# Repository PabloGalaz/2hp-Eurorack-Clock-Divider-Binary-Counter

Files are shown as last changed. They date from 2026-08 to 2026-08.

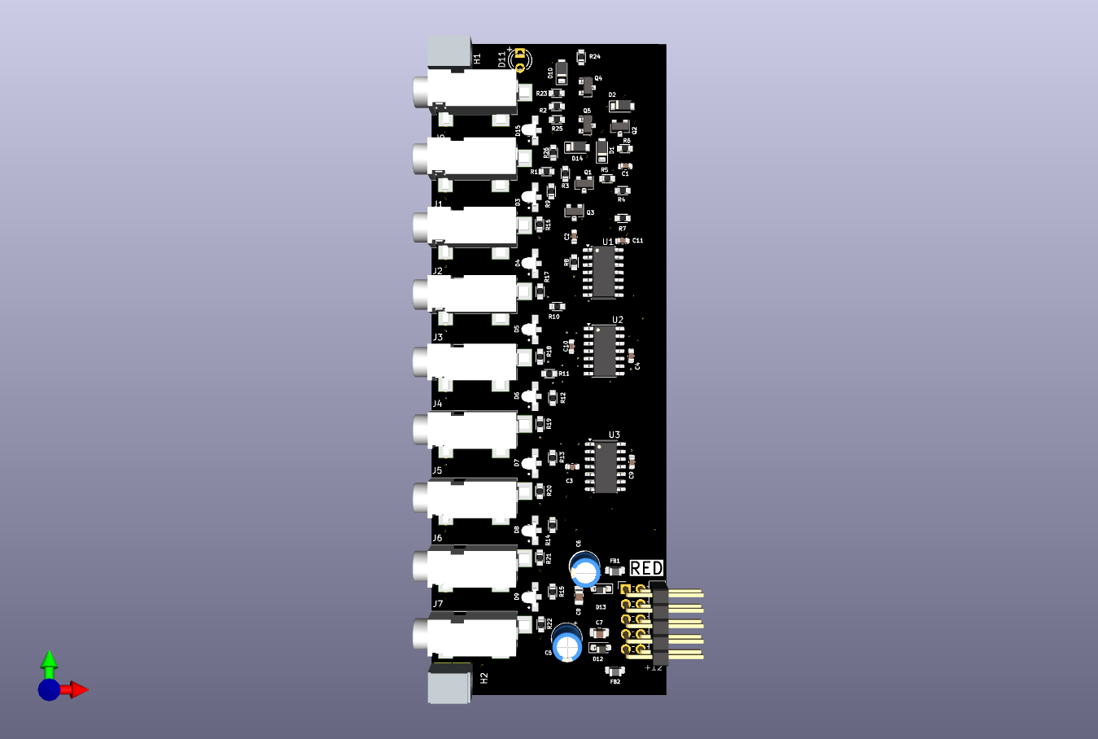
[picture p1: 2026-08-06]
Images/Clock_Div_Bin_Counter-2HP_V1_BOARD.png

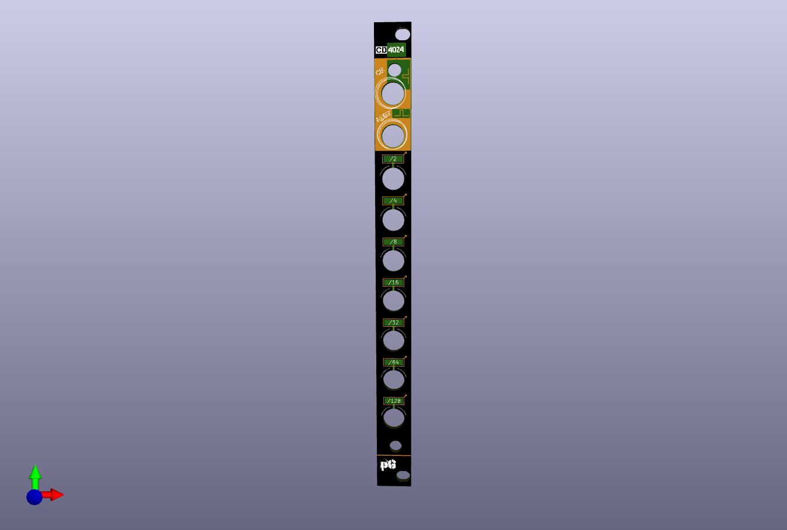
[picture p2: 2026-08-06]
Images/Clock_Div_Bin_Counter-2HP_V1_PANEL.png

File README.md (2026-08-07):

# 2hp-Eurorack-Clock-Divider-Binary-Counter

Slim CD4024-based Eurorack Clock Divider/Binary Counter derived from a schematic by PolyKit (https://polykit.rocks/eurorack-clock-divider-module-modular-synth-diy/), with the following differences:

- 2hp (instead of 4hp)
- Mostly SMD components (0603)
- Added /128 output
- Added LED for clock input (through-hole, bent; watch video)
- Only one board

The PCB layout was inspired by the PCB layout of Uncertainty, by OAM (https://github.com/oamodular/uncertainty.git)

Version 2 is the only one that has been manufactured and tested. This version has a footprint error that can be fixed by carefully bending the legs of the five MMBT3904 transistors (SOT-23-3) and soldering them upside down (!). It's easier than it sounds, and it will work. Version 3 has that error fixed, but has not been tested yet.

BUILD THIS AT YOUR OWN RISK. FILES PROVIDED "AS IS", WITHOUT WARRANTY OF ANY KIND.

Watch the video (https://www.youtube.com/shorts/lrMSy79it8Q)

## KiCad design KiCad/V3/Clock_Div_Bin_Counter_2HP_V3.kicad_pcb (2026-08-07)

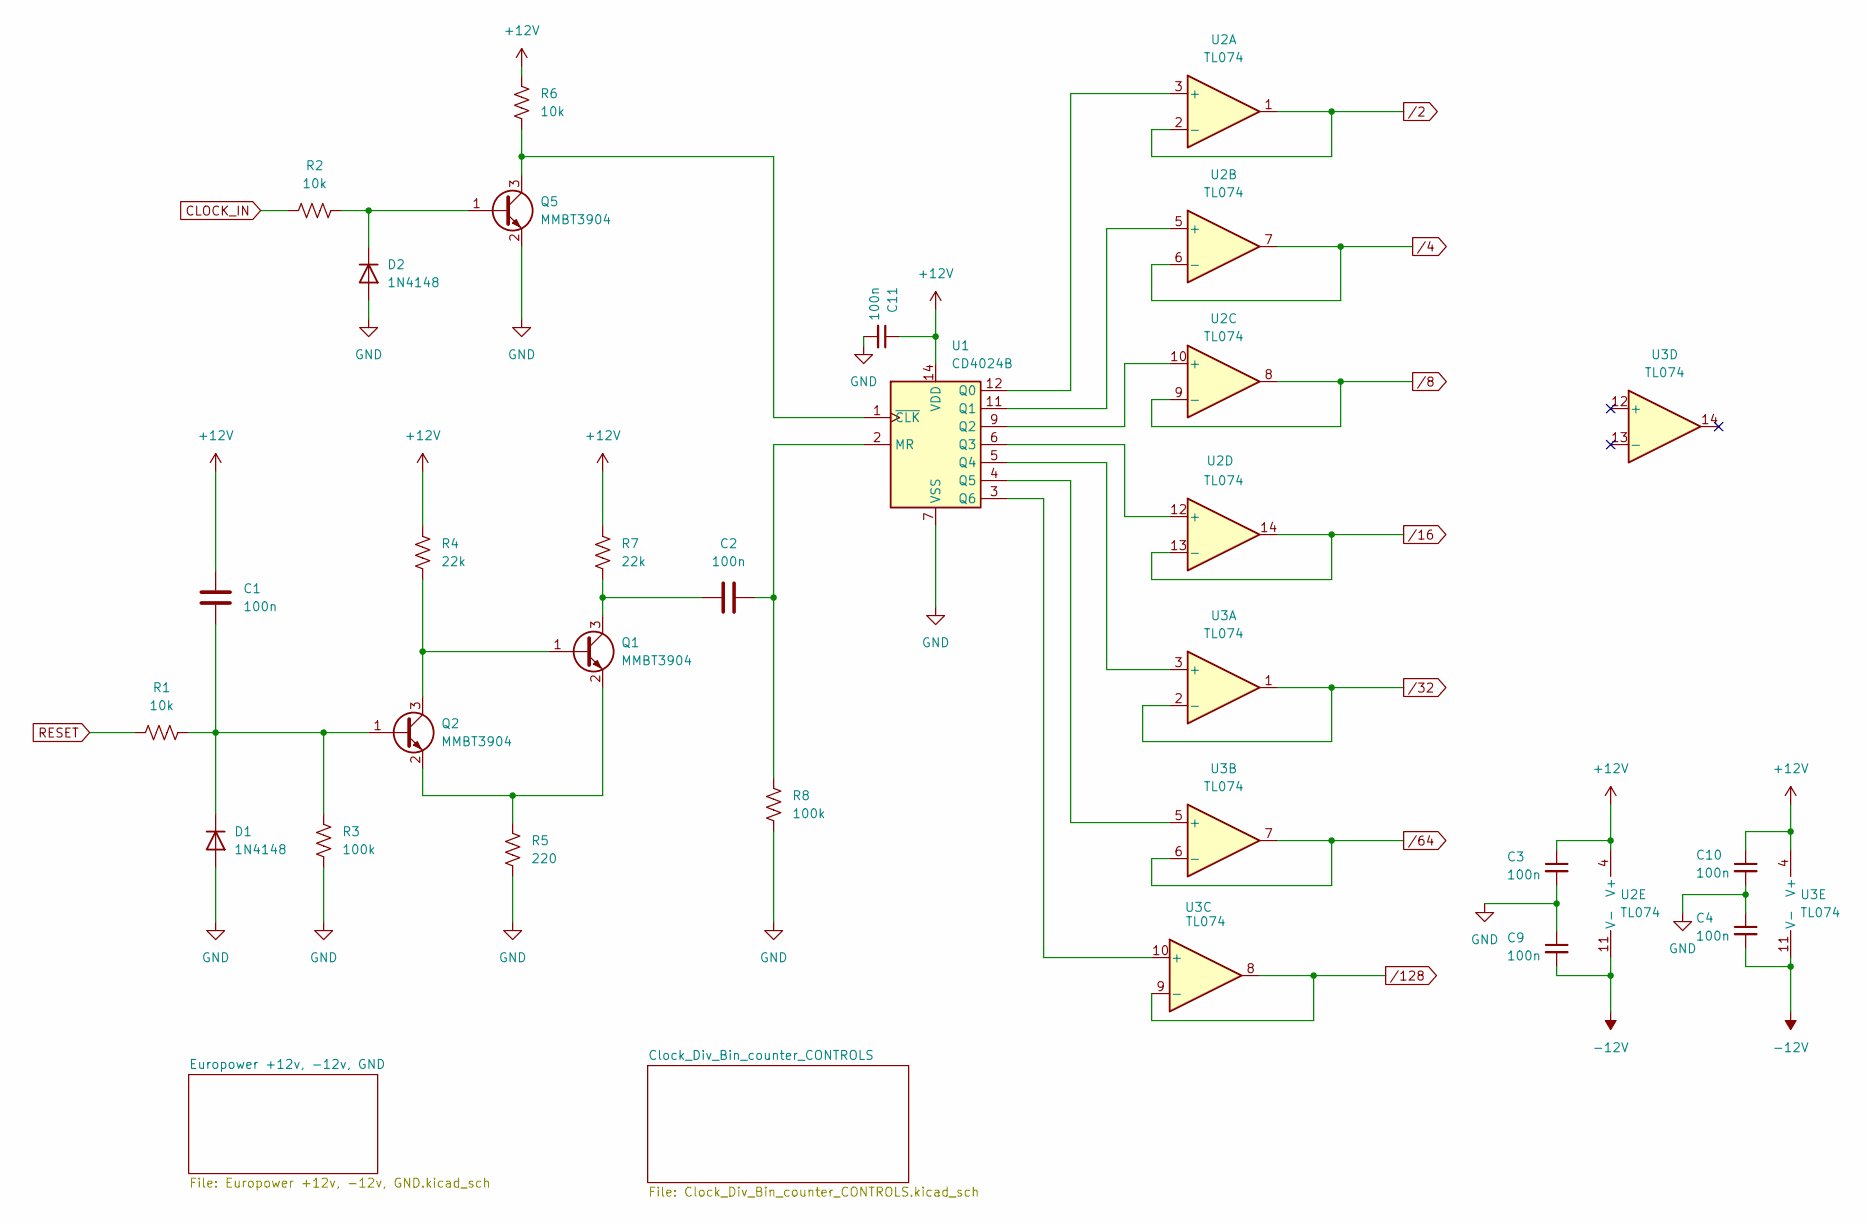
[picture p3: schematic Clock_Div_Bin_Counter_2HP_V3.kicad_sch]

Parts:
C1, C2, C3, C4, C9, C10, C11: 100n; C_0603_1608Metric
D1, D2: 1N4148; Nexperia_CFP3_SOD-123W
Q1, Q2, Q5: MMBT3904; SOT-23
R1, R2, R6: 10k; R_0603
R3, R8: 100k; R_0603
R4, R7: 22k; R_0603
R5: 220; R_0603
U1: CD4024B; SOIC-14_3.9x8.7mm_P1.27mm
U2, U3: TL074; SOIC-14_3.9x8.7mm_P1.27mm

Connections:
+12V: C1.1, C3.1, C10.1, C11.1, R4.2, R6.2, R7.2, U1.14 (VDD), U2.4 (V+), U3.4 (V+); also elsewhere on the board
-12V: C4.2, C9.2, U2.11 (V-), U3.11 (V-); also elsewhere on the board
CLOCK_IN: R2.1; also elsewhere on the board
GND: C3.2, C4.1, C9.1, C10.2, C11.2, D1.2 (A), D2.2 (A), Q5.2 (E), R3.1, R5.1, R8.1, U1.7 (VSS); also elsewhere on the board
unnamed: C1.2, D1.1 (K), Q2.1 (B), R1.2, R3.2
unnamed: D2.1 (K), Q5.1 (B), R2.2
unnamed: Q1.1 (B), Q2.3 (C), R4.1
unnamed: C2.1, Q1.3 (C), R7.1
unnamed: Q1.2 (E), Q2.2 (E), R5.2
unnamed: Q5.3 (C), R6.1, U1.1 (~CLK)
unnamed: C2.2, R8.2, U1.2 (MR)
unnamed: U1.12 (Q0), U2.3 (+)
unnamed: U1.11 (Q1), U2.5 (+)
unnamed: U1.9 (Q2), U2.10 (+)
unnamed: U1.6 (Q3), U2.12 (+)
unnamed: U1.5 (Q4), U3.3 (+)
unnamed: U1.4 (Q5), U3.5 (+)
unnamed: U1.3 (Q6), U3.10 (+)
RESET: R1.1; also elsewhere on the board
/2: U2.1, U2.2 (-); also elsewhere on the board
/4: U2.6 (-), U2.7; also elsewhere on the board
/8: U2.8, U2.9 (-); also elsewhere on the board
/16: U2.13 (-), U2.14; also elsewhere on the board
/32: U3.1, U3.2 (-); also elsewhere on the board
/64: U3.6 (-), U3.7; also elsewhere on the board
/128: U3.8, U3.9 (-); also elsewhere on the board

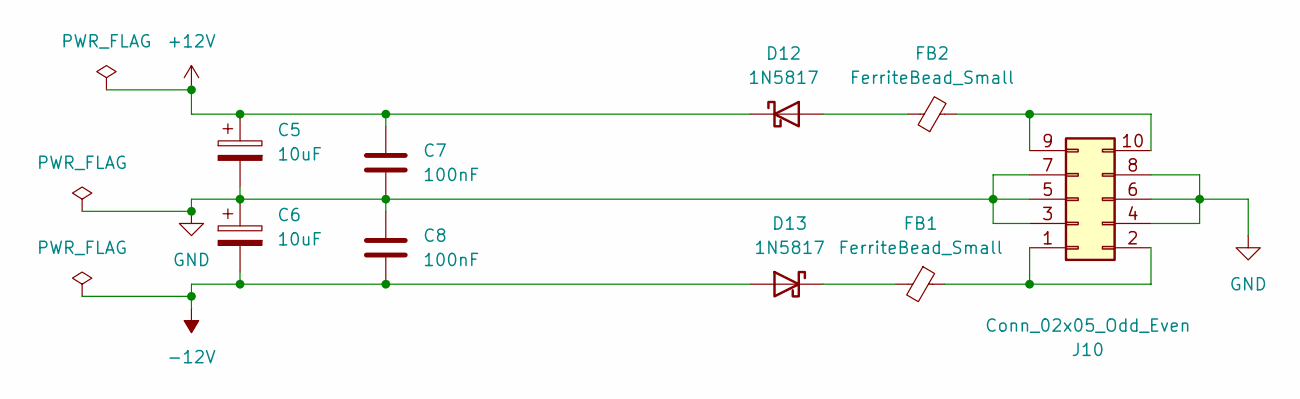
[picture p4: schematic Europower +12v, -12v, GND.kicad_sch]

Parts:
C5, C6: 10uF; CP_Radial_D5.0mm_P2.00mm
C7, C8: 100nF; C_0805_2012Metric_Pad1.18x1.45mm_HandSolder
D12, D13: 1N5817; D_SOD-323_HandSoldering
FB1, FB2: FerriteBead_Small; L_0805_2012Metric_Pad1.05x1.20mm_HandSolder
J10: Conn_02x05_Odd_Even; PinHeader_2x05_P2.54mm_Horizontal

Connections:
+12V: C5.1, C7.1, D12.1 (K); also elsewhere on the board
-12V: C6.2, C8.2, D13.2 (A); also elsewhere on the board
GND: C5.2, C6.1, C7.2, C8.1, J10.3, J10.4, J10.5, J10.6, J10.7, J10.8; also elsewhere on the board
unnamed: D12.2 (A), FB2.1
unnamed: D13.1 (K), FB1.2
unnamed: FB1.1, J10.1, J10.2
unnamed: FB2.2, J10.9, J10.10

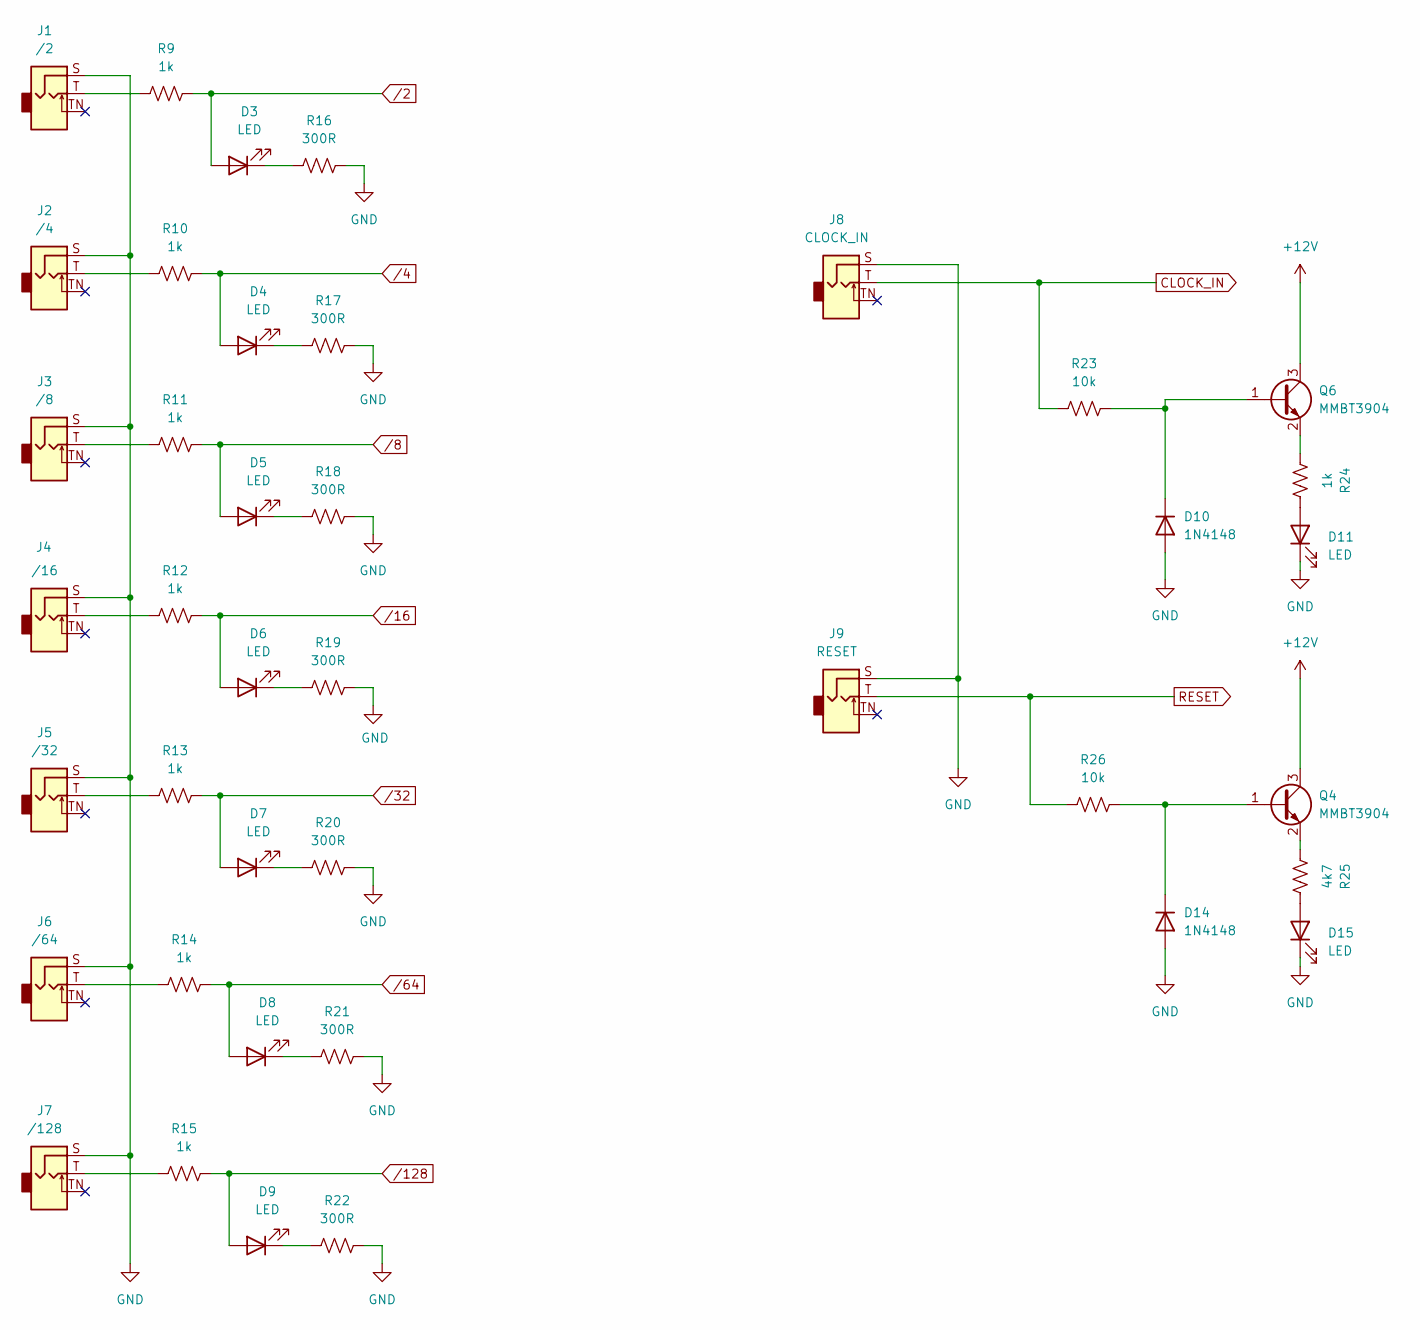
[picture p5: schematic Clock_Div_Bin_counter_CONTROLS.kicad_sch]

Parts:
D3, D4, D5, D6, D7, D8, D9, D15: LED; LED-SMD Red SideEmit Angle30 3x1mm -APPA3010SURCK
D10, D14: 1N4148; Nexperia_CFP3_SOD-123W
D11: LED; LED_3mm_C1A2_Polarity_Indicator
J1: /2; SWITCHCRAFT_35RASMT2AHNTRX; MPN 35RASMT2AHNTRX
J2: /4; SWITCHCRAFT_35RASMT2AHNTRX; MPN 35RASMT2AHNTRX
J3: /8; SWITCHCRAFT_35RASMT2AHNTRX; MPN 35RASMT2AHNTRX
J4: /16; SWITCHCRAFT_35RASMT2AHNTRX; MPN 35RASMT2AHNTRX
J5: /32; SWITCHCRAFT_35RASMT2AHNTRX; MPN 35RASMT2AHNTRX
J6: /64; SWITCHCRAFT_35RASMT2AHNTRX; MPN 35RASMT2AHNTRX
J7: /128; SWITCHCRAFT_35RASMT2AHNTRX; MPN 35RASMT2AHNTRX
J8: CLOCK_IN; SWITCHCRAFT_35RASMT2AHNTRX; MPN 35RASMT2AHNTRX
J9: RESET; SWITCHCRAFT_35RASMT2AHNTRX; MPN 35RASMT2AHNTRX
Q4, Q6: MMBT3904; SOT-23
R9, R10, R11, R12, R13, R14, R15, R24: 1k; R_0603
R16, R17, R18, R19, R20, R21, R22: 300R; R_0603
R23, R26: 10k; R_0603
R25: 4k7; R_0603

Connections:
+12V: Q4.3 (C), Q6.3 (C); also elsewhere on the board
CLOCK_IN: J8.T (Tip), R23.1; also elsewhere on the board
GND: D10.2 (A), D11.1 (K), D14.2 (A), D15.1 (K), J1.S (Sleeve), J2.S (Sleeve), J3.S (Sleeve), J4.S (Sleeve), J5.S (Sleeve), J6.S (Sleeve), J7.S (Sleeve), J8.S (Sleeve), J9.S (Sleeve), R16.2, R17.2, R18.2, R19.2, R20.2, R21.2, R22.2; also elsewhere on the board
unnamed: D3.1 (K), R16.1
unnamed: D4.1 (K), R17.1
unnamed: D5.1 (K), R18.1
unnamed: D6.1 (K), R19.1
unnamed: D7.1 (K), R20.1
unnamed: D8.1 (K), R21.1
unnamed: D9.1 (K), R22.1
unnamed: D10.1 (K), Q6.1 (B), R23.2
unnamed: D11.2 (A), R24.2
unnamed: D14.1 (K), Q4.1 (B), R26.2
unnamed: D15.2 (A), R25.2
unnamed: J1.T (Tip), R9.1
unnamed: J2.T (Tip), R10.1
unnamed: J3.T (Tip), R11.1
unnamed: J4.T (Tip), R12.1
unnamed: J5.T (Tip), R13.1
unnamed: J6.T (Tip), R14.1
unnamed: J7.T (Tip), R15.1
unnamed: Q4.2 (E), R25.1
unnamed: Q6.2 (E), R24.1
RESET: J9.T (Tip), R26.1; also elsewhere on the board
/2: D3.2 (A), R9.2; also elsewhere on the board
/4: D4.2 (A), R10.2; also elsewhere on the board
/8: D5.2 (A), R11.2; also elsewhere on the board
/16: D6.2 (A), R12.2; also elsewhere on the board
/32: D7.2 (A), R13.2; also elsewhere on the board
/64: D8.2 (A), R14.2; also elsewhere on the board
/128: D9.2 (A), R15.2; also elsewhere on the board

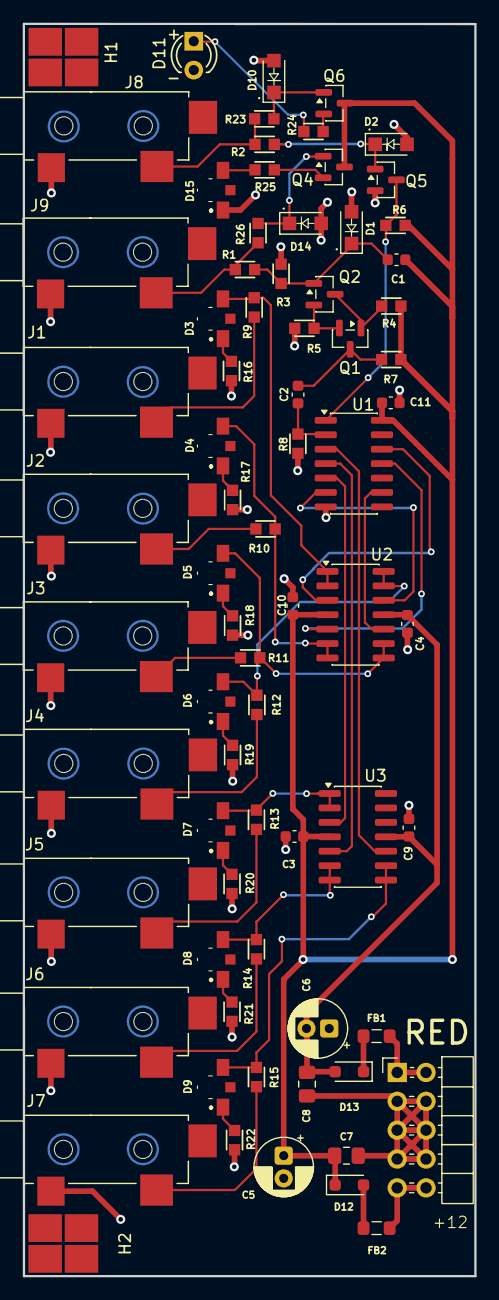
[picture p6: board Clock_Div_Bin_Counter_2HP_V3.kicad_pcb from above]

Board: 2 copper layers, 39.8 x 110.2 mm, 74 parts (0 on the bottom side), 50 nets.

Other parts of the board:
H1, H2: Wurth 7466303; WP-SMRA_7466303
